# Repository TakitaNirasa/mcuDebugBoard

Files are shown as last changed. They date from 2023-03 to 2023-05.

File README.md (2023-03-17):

# Отладочная плата
### Назначение
Унивесальная плата для разработки простых дешёвых встраиваемых устройств либо как вспомагательная плата в более сложной системе.
Архитектура платы представлена ниже:

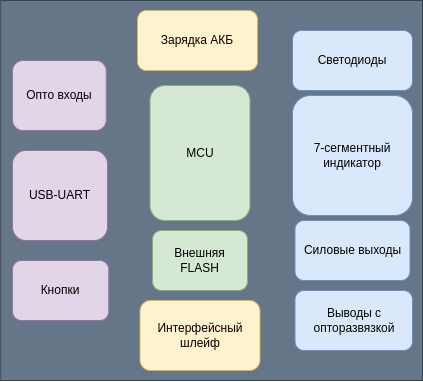
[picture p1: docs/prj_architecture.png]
Пикча


### Задачи поставленные перед платой:
  * Максимальная дешивизна и простота в покупке компонентов
  * "Универсальность без излишеств"
  * Возможность подключения периферии без мотка проводов
  * Наличие как обычного ввода-вывода, так и опторазвязанного
  * Наличие "силовой части" управления нагрузкой
  * Кнопки и индикация на плате
  * Модуль зарядки аккумулятора с защитой

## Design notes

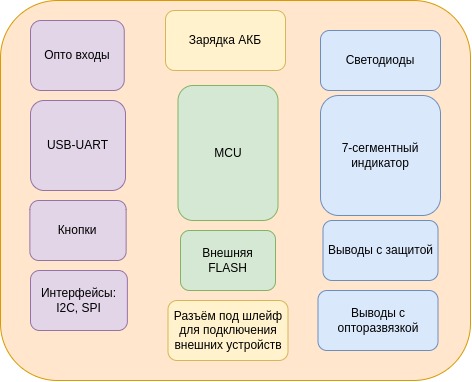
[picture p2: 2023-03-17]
docs/prj_architecture.jpg

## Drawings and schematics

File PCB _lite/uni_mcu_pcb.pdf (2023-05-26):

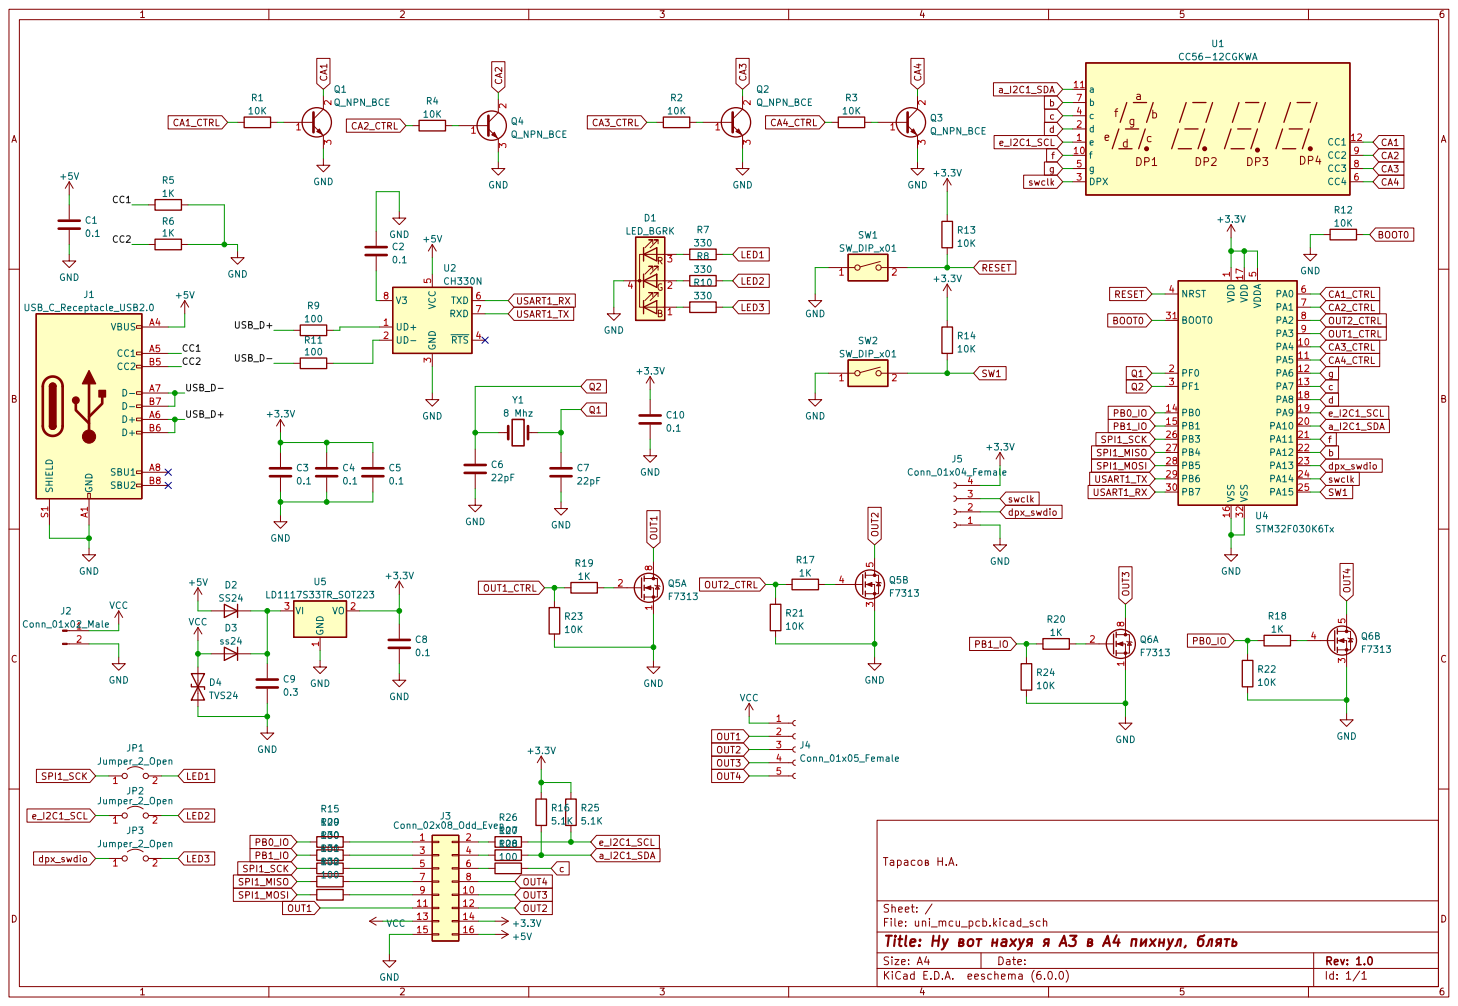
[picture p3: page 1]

1 PA4 10 PA5 11 PA6 12 PA7 13 PB0 14 PB1 15 VSS 16 VDD 17 PA8 18 PA9 19 PF0 2 PA10 20 PA11 21 PA12 22 PA13 23 PA14 24 PA15 25 PB3 26 PB4 27 PB5 28 PB6 29 PF1 3 PB7 30 BOOT0 31 VSS 32 NRST 4 VDDA

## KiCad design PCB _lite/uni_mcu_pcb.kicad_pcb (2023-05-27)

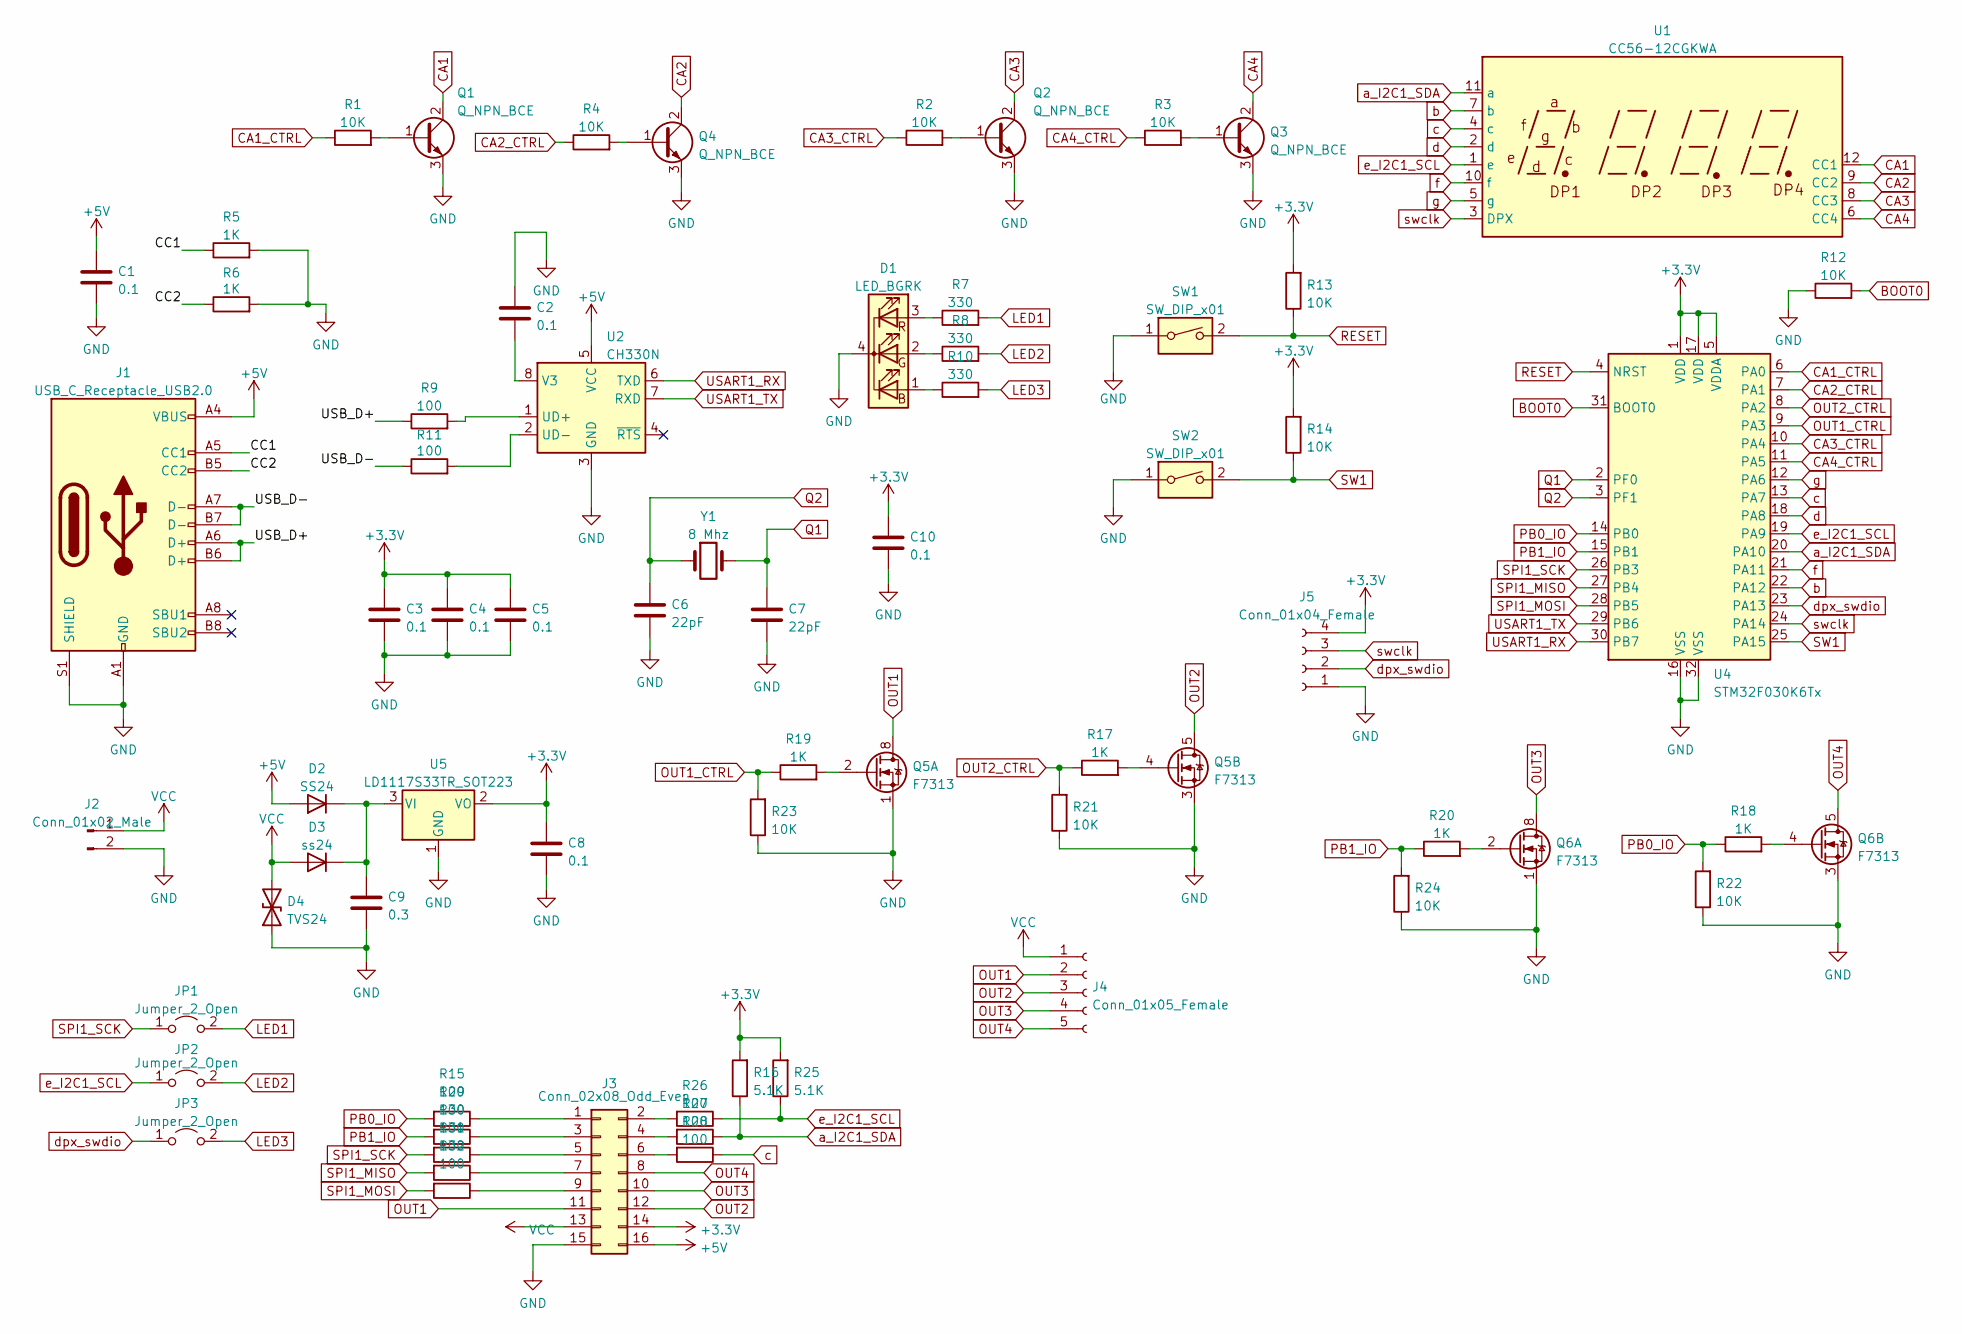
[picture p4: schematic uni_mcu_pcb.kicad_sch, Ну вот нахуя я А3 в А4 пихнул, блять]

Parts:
C1, C2, C3, C4, C5, C8, C10: 0.1; C_0603_1608Metric_Pad1.08x0.95mm_HandSolder
C6, C7: 22pF; C_0603_1608Metric_Pad1.08x0.95mm_HandSolder
C9: 0.3; C_0603_1608Metric_Pad1.08x0.95mm_HandSolder
D1: LED_BGRK; LED_RGB_1210
D2: SS24; D_SMB
D3: ss24; D_SMB
D4: TVS24; D_SMB
J1: USB_C_Receptacle_USB2.0; USB_C_Receptacle_GCT_USB4105-xx-A_16P_TopMnt_Horizontal
J2: Conn_01x02_Male; TerminalBlock_MetzConnect_Type011_RT05502HBWC_1x02_P5.00mm_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
J3: Conn_02x08_Odd_Even; IDC-Header_2x08_P2.54mm_Vertical
J4: Conn_01x05_Female; TerminalBlock_MetzConnect_Type011_RT05505HBWC_1x05_P5.00mm_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
J5: Conn_01x04_Female; Hirose_DF11-4DP-2DSA_2x02_P2.00mm_Vertical
JP1, JP2, JP3: Jumper_2_Open; SolderJumper-2_P1.3mm_Open_TrianglePad1.0x1.5mm
Q1, Q2, Q3, Q4: Q_NPN_BCE; SOT-23-3
Q5, Q6: F7313; SOIC-8_3.9x4.9mm_P1.27mm
R1, R2, R3, R4, R12, R13, R14, R21, R22, R23, R24: 10K; R_0603_1608Metric_Pad0.98x0.95mm_HandSolder
R5, R6, R17, R18, R19, R20: 1K; R_0603_1608Metric_Pad0.98x0.95mm_HandSolder
R7, R8, R10: 330; R_0603_1608Metric_Pad0.98x0.95mm_HandSolder
R9, R11, R15, R26, R27, R28, R29, R30, R31, R32: 100; R_0603_1608Metric_Pad0.98x0.95mm_HandSolder
R16, R25: 5.1K; R_0603_1608Metric_Pad0.98x0.95mm_HandSolder
SW1, SW2: SW_DIP_x01; SW_SPST_CK_RS282G05A3
U1: CC56-12CGKWA; CA56-12CGKWA
U2: CH330N; SOIC-8_3.9x4.9mm_P1.27mm
U4: STM32F030K6Tx; LQFP-32_7x7mm_P0.8mm
U5: LD1117S33TR_SOT223; SOT-223-3_TabPin2
Y1: 8 Mhz; Crystal_HC49-4H_Vertical

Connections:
+3V3: C3.1, C4.1, C5.1, C8.1, C10.1, J3.14, J5.4, R13.2, R14.2, R16.2, R25.2, U4.1 (VDD), U4.5 (VDDA), U4.17 (VDD), U5.2 (VO)
+5V: C1.1, D2.1 (A), J1.A4 (VBUS), J1.A9 (VBUS), J1.B4 (VBUS), J1.B9 (VBUS), J3.16, U2.5 (VCC)
/CC1: J1.A5 (CC1), R5.1
/CC2: J1.B5 (CC2), R6.1
/USB_D+: J1.A6 (D+), J1.B6 (D+), R9.1
/USB_D-: J1.A7 (D-), J1.B7 (D-), R11.1
BOOT0: R12.2, U4.31 (BOOT0)
CA1: Q1.2 (C), U1.12 (CC1)
CA1_CTRL: R1.1, U4.6 (PA0)
CA2: Q4.2 (C), U1.9 (CC2)
CA2_CTRL: R4.1, U4.7 (PA1)
CA3: Q2.2 (C), U1.8 (CC3)
CA3_CTRL: R2.1, U4.10 (PA4)
CA4: Q3.2 (C), U1.6 (CC4)
CA4_CTRL: R3.1, U4.11 (PA5)
GND: C1.2, C2.1, C3.2, C4.2, C5.2, C6.1, C7.2, C8.2, C9.2, C10.2, D1.4 (K), D4.1 (A1), J1.A1 (GND), J1.A12 (GND), J1.B1 (GND), J1.B12 (GND), J1.S1 (SHIELD), J2.2, J3.15, J5.1, Q1.3 (E), Q2.3 (E), Q3.3 (E), Q4.3 (E), Q5.1 (S1), Q5.3 (S2), Q6.1 (S1), Q6.3 (S2), R5.2, R6.2, R12.1, R21.1, R22.1, R23.1, R24.1, SW1.1, SW2.1, U2.3 (GND), U4.16 (VSS), U4.32 (VSS), U5.1 (GND)
LED1: JP1.2 (B), R7.2
LED2: JP2.2 (B), R8.2
LED3: JP3.2 (B), R10.2
unnamed: C2.2, U2.8 (V3)
unnamed: C9.1, D2.2 (K), D3.2 (K), U5.3 (VI)
unnamed: D1.1 (BA), R10.1
unnamed: D1.2 (GA), R8.1
unnamed: D1.3 (RA), R7.1
unnamed: J3.1, R15.1
unnamed: J3.2, R26.2
unnamed: J3.3, R29.1
unnamed: J3.4, R27.2
unnamed: J3.5, R30.1
unnamed: J3.6, R28.2
unnamed: J3.7, R31.1
unnamed: J3.9, R32.1
unnamed: Q1.1 (B), R1.2
unnamed: Q2.1 (B), R2.2
unnamed: Q3.1 (B), R3.2
unnamed: Q4.1 (B), R4.2
unnamed: Q5.2 (G1), R19.2
unnamed: Q5.4 (G2), R17.2
unnamed: Q6.2 (G1), R20.2
unnamed: Q6.4 (G2), R18.2
unnamed: R9.2, U2.1 (UD+)
unnamed: R11.2, U2.2 (UD-)
OUT1: J3.11, J4.2, Q5.7 (D1), Q5.8 (D1)
OUT1_CTRL: R19.1, R23.2, U4.9 (PA3)
OUT2: J3.12, J4.3, Q5.5 (D2), Q5.6 (D2)
OUT2_CTRL: R17.1, R21.2, U4.8 (PA2)
OUT3: J3.10, J4.4, Q6.7 (D1), Q6.8 (D1)
OUT4: J3.8, J4.5, Q6.5 (D2), Q6.6 (D2)
PB0_IO: R15.2, R18.1, R22.2, U4.14 (PB0)
PB1_IO: R20.1, R24.2, R29.2, U4.15 (PB1)
Q1: C7.1, U4.2 (PF0), Y1.2
Q2: C6.2, U4.3 (PF1), Y1.1
RESET: R13.1, SW1.2, U4.4 (NRST)
SPI1_MISO: R31.2, U4.27 (PB4)
SPI1_MOSI: R32.2, U4.28 (PB5)
SPI1_SCK: JP1.1 (A), R30.2, U4.26 (PB3)
SW1: R14.1, SW2.2, U4.25 (PA15)
USART1_RX: U2.6 (TXD), U4.30 (PB7)
USART1_TX: U2.7 (RXD), U4.29 (PB6)
VCC: D3.1 (A), D4.2 (A2), J2.1, J3.13, J4.1
a_I2C1_SDA: R16.1, R27.1, U1.11 (a), U4.20 (PA10)
b: U1.7 (b), U4.22 (PA12)
c: R28.1, U1.4 (c), U4.13 (PA7)
d: U1.2 (d), U4.18 (PA8)
dpx_swdio: J5.2, JP3.1 (A), U4.23 (PA13)
e_I2C1_SCL: JP2.1 (A), R25.1, R26.1, U1.1 (e), U4.19 (PA9)
f: U1.10 (f), U4.21 (PA11)
g: U1.5 (g), U4.12 (PA6)
swclk: J5.3, U1.3 (DPX), U4.24 (PA14)

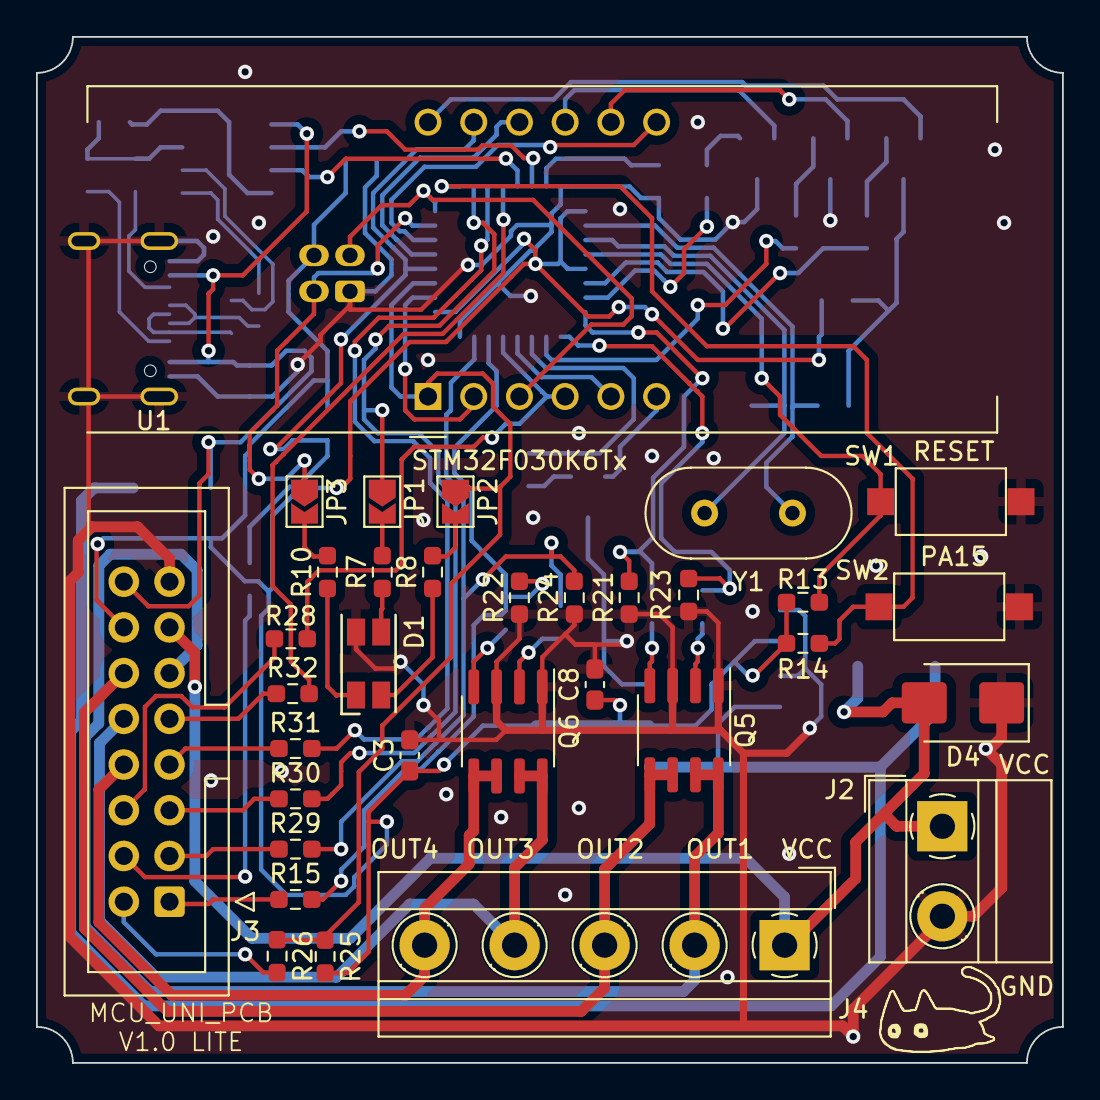
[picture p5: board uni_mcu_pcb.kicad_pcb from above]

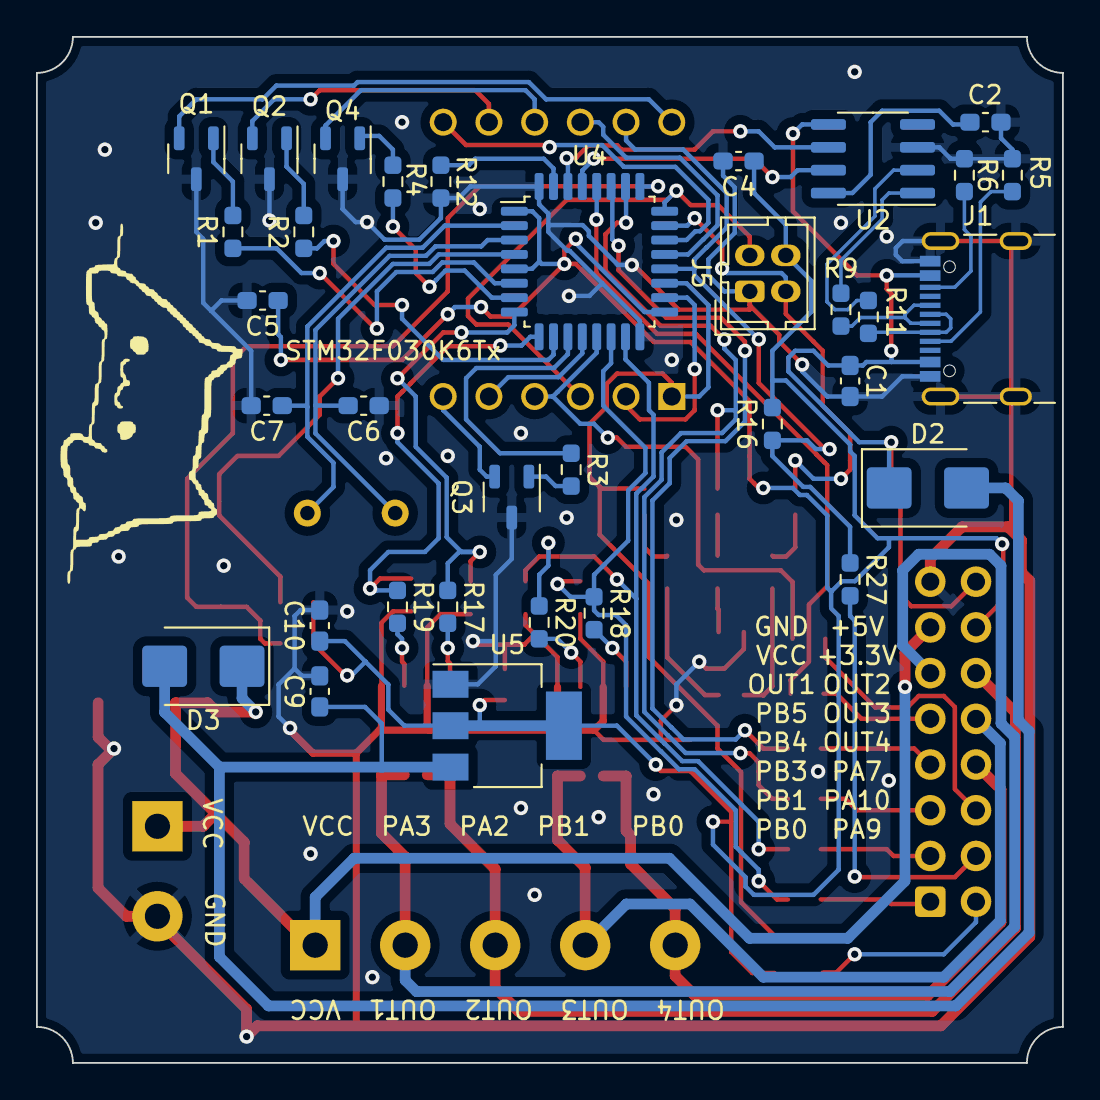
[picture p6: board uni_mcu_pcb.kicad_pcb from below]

Board: 2 copper layers, 57.0 x 57.0 mm, 67 parts (34 on the bottom side), 69 nets.

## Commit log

2023-03-17 Первый коммит
    [uni_mcu_pcb.kicad_pcb, uni_mcu_pcb.kicad_sch]
2023-03-17 Пикча
2023-03-17 Добавлены некоторые компоненты на плату
    [uni_mcu_pcb.kicad_sch]
2023-03-21 Схемотехника разработана на 80%
    [uni_mcu_pcb.kicad_sch]
2023-03-21 Добавлено управление нагрузкой
    [uni_mcu_pcb.kicad_sch]
2023-03-23 Добавлен кварц. Нужно добавить модуль заряда
    [uni_mcu_pcb.kicad_sch]
2023-03-23 Добавлен ещё один контроллер, но в QFP32 корпусе
    [uni_mcu_pcb.kicad_sch]
2023-03-24 Начата разводка платы
    [uni_mcu_pcb.kicad_pcb, uni_mcu_pcb.kicad_sch]
2023-03-27 Добавлены библиотеки для зарядки li-ion
    [uni_mcu_pcb.kicad_sch]
2023-03-31 Разводка модуля зарядки li-ion
    [uni_mcu_pcb.kicad_sch]
2023-05-24 Добавлена lite версия платы
    [uni_mcu_pcb.kicad_pcb, uni_mcu_pcb.kicad_sch]
2023-05-24 Частично разведена плата
    [uni_mcu_pcb.kicad_pcb, uni_mcu_pcb.kicad_sch]
2023-05-25 разведена плата
    [uni_mcu_pcb.kicad_pcb, uni_mcu_pcb.kicad_sch]
2023-05-26 Расставлены номиналы
    [uni_mcu_pcb.kicad_pcb, uni_mcu_pcb.kicad_sch]
2023-05-26 Отредактирована распиновка, доделана шелкография
    [uni_mcu_pcb.kicad_pcb, uni_mcu_pcb.kicad_sch]
2023-05-26 Схема теперь А4, Сформированы герберы
    [uni_mcu_pcb-B_Cu.gbr, uni_mcu_pcb-B_Mask.gbr, uni_mcu_pcb-B_Paste.gbr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]
2023-05-26 Утолщение кота
    [uni_mcu_pcb.kicad_pcb]
2023-05-27 Правка 3д и добавлен скрин модели
    [uni_mcu_pcb.kicad_pcb]
